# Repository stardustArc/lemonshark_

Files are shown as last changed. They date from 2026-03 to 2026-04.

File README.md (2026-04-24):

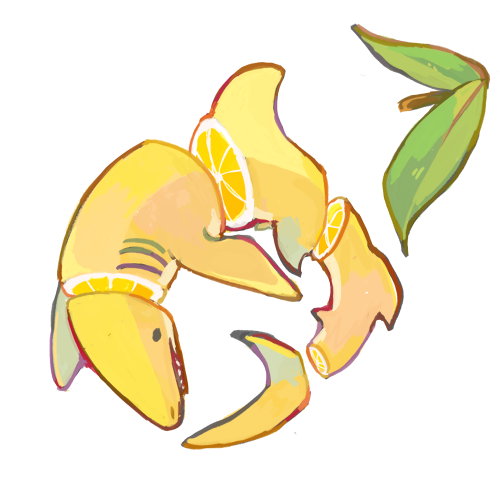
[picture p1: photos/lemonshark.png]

# lemonshark

a wireless split keyboard with per-key RGB and nice!view displays

---
## to do
- [ ] write readme (this is gonna take a lot of commits lol)
- [ ] upload images/gallery
- [ ] modify logo image to be cleaner (light mode jumpscare rn)
- [ ] create v2 PCB
- [ ] build guide?
- [ ] user-mods/cases (pyntie's case + plateless + OLED-compatible display cover)
- [ ] clean up ZMK config/readme/keymap (need to add link to this)

---
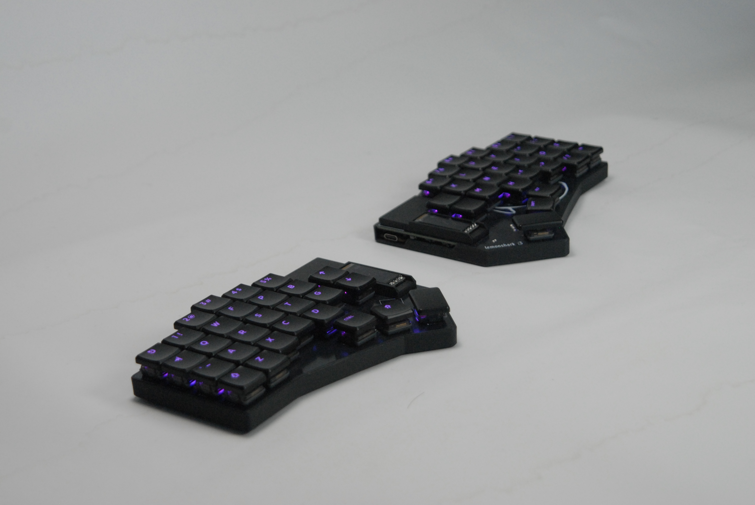
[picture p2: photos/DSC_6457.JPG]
main photo


▲ lemonshark with plateless case, RGB, and MBK glow

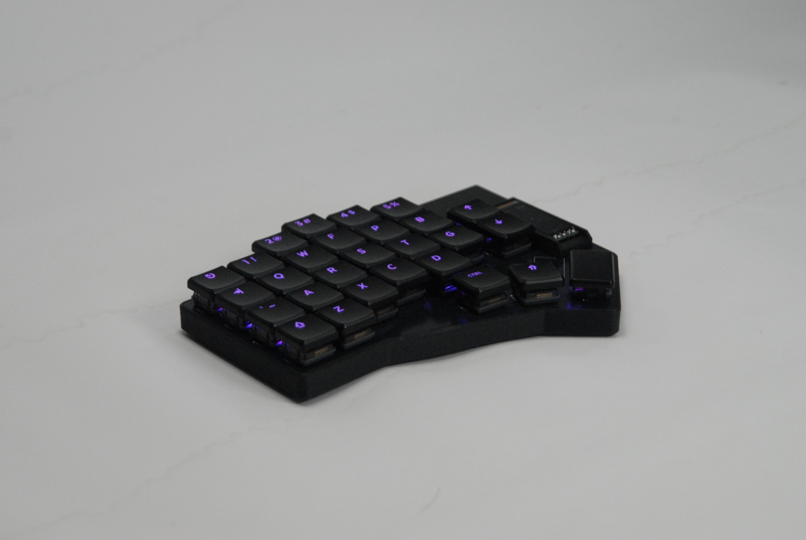
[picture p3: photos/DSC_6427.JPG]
left_RGB


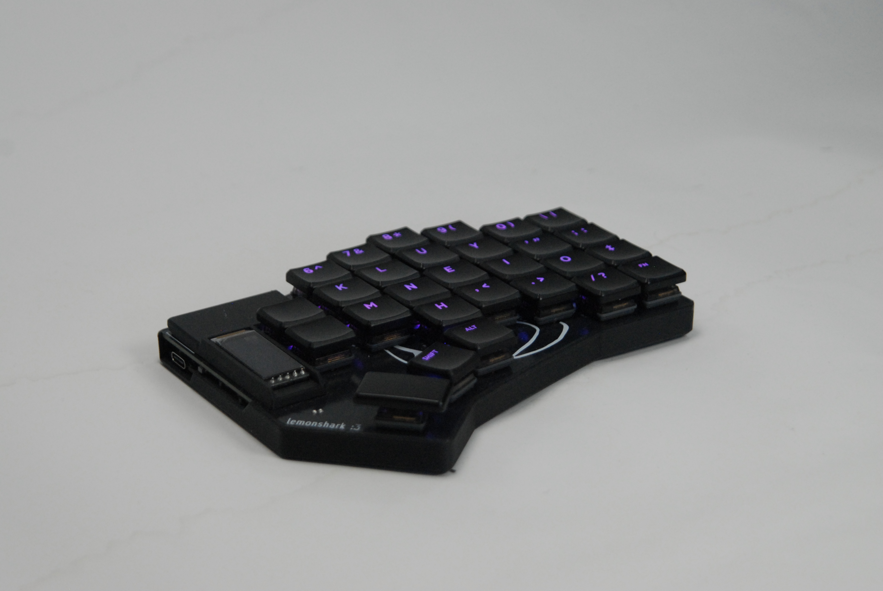
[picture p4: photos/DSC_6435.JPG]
right_RGB


---
## features:
- choc v1 compatible
- wireless
- nice!view-compatible displays
- per-key RGB
- extra-large battery

---
## ZMK config

need to clean up the [repo](https://github.com/stardustArc/zmk-config-lemonsharkv2) but here it is

---
## V1 BOM

| Part | Count | Desc | Source |
| --- | --- |--- | --- |
| Left PCB | 1 | | Your preferred fab, or message me, there's always a chance I have spare boards |
| Right PCB | 1 | | same as above |
| nice!nano v2 | 2 | MCU, though any wireless Pro Micro-based MCU will work | [Typeractive (real)](https://typeractive.xyz/products/nice-nano) or [Amazon (clone)](https://www.amazon.com/Teyleten-Robot-Development-Bluetooth-Management/dp/B0CYLNZ6V4) |
| nice!view | 2 | display, vertical SSD1306 OLEDs are also compatible | [Typeractive (nice!view)](https://typeractive.xyz/products/nice-view) or [Amazon (OLED)](https://www.amazon.com/MakerFocus-Display-SSD1306-3-3V-5V-Arduino/dp/B079BN2J8V?th=1)
| Batteries | 1 | PS3 replacement batteries, comes in a 2pk | [Amazon](https://www.amazon.com/Replacement-Playstation-Controller-CECHZC2E-CECHZC2U-3/dp/B09726K2LC) |
| Choc V1 | 56 | switches, **choc V2 NOT compatible** | [Ambient Twilights](https://lowprokb.ca/collections/switches/products/ambients-silent-choc-switches?variant=44873426436260) you don't have to use these obviously, I just like them |
| Hotswap sockets | 56 | choc hotswap switches | [Amazon](https://www.amazon.com/Mechkeeb-Kailh-Low-Hot-swappable-Socket/dp/B0BS3JYJJQ?th=1) |
| 1N4148W SOD-123F | 56 | SMD diodes, buy spares (like 60) | [Digikey](https://www.digikey.com/en/products/detail/diotec-semiconductor/1N4148W/18833653) |
| EVQ-PUA02K | 2 | reset button | [Digikey](https://www.digikey.com/en/products/detail/panasonic-electronic-components/EVQ-PUA02K/286334) |
| SSSS811101 | 4 | power switch | [Digikey](https://www.digikey.com/en/products/detail/alps-alpine/SSSS811101/19529062) |
| S2B-PH-K-S | 2 | right angle male 2mm JST-PH connector| [Digikey](https://www.digikey.com/en/products/detail/jst-sales-america-inc/S2B-PH-K-S/926626) |
| Mill-Max 310-47-112-41-001000 | 5 | machine pin header for MCU and display | [Digikey](https://www.digikey.com/en/products/detail/mill-max-manufacturing-corp/310-47-112-41-001000/7364039) |
| Mill-Max 3320-0-00-15-00-00-03-0 | 65 | pins for headers, this count includes 7 spares | [Digikey](https://www.digikey.com/en/products/detail/mill-max-manufacturing-corp/3320-0-00-15-00-00-03-0/4147392) |
| Adafruit MiniBoost 5V TPS61023 | 2 | level shifter for LEDs | [Digikey](https://www.digikey.com/en/products/detail/adafruit-industries-llc/4654/12697636) |
| SK6812 Mini-E | 56 | LEDs, best to use SK6803 but it's not what I had, plus these were dirt cheap | [Amazon](https://www.amazon.com/Lizusidtsy-Similar-Individually-Addressable-500076361/dp/B0D62PYX62) |
| Keycaps of your choice | 56 | 54 1u keys, 2 1.5u keys. Choc-spaced | take your pick! MBK Legends Glow R1 for me |
| Case | 2 | one of each half | located in this repository |

---
## Credits

A massive thank you to the MrZealot and [Ceoloide](https://github.com/ceoloide) for creating and maintaining [Ergogen](https://ergogen.xyz), the software with which lemonshark was created. The [Absolem Club discord](http://discord.ergogen.xyz/) was irreplacable for help of all sorts, as was FlatFootFox with his [writeup](https://flatfootfox.com/ergogen-introduction/) on Ergogen. Additonally, thank you to car, Evelyn, [Peter](https://github.com/peterjc/), Fox, Turtlyn, and [Grinnie](https://github.com/regicidalplutophage) from Absolem Club, they were all a massive help in getting through this monumental project.

Thanks to Genteure and their [ZMK Shield Wizard](https://shield-wizard.genteure.workers.dev/), it made configuring ZMK a breeze. Also, thanks to the entire team behind the [ZMK firmware](https://zmk.dev), one of the main goals of this board wouldn't be possible without you.

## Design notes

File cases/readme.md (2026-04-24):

## cases

--- 

lemonshark currently has two case options:
  - a low profile, hardwareless case which fits both the nice!view and other OLEDs. Requires some foam strips to secure the battery.
    (insert photo here. this is the case found on the main readme)
    
  - a case by PyntieHet, which is far prettier but less low profile (STLs only)   (please note I do not have the files for this yet, will update when I do)
    (insert photo here)

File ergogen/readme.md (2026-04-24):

# Ergogen stuff

---

lemonshark was created in Ergogen, with silkscreens and level shifter added in KiCAD.

Here are all of the local footprint I used, along with the config file.
I plan on cleaning up the config file at some point, it's pretty messy right now.

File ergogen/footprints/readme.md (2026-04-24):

You will need to import the following footprints into Ergogen and rename them so that the footprint name is the same as the file name. 

---
## Note:

These footprints _should_ all render in KiCavas, I've updated them all to KiCAD 8.

Additionally, the level shift was a custom footprint I designed in KiCAD, I've since lost the footprint as my laptop's SSD decided to die.

(I plan on either not requiring the level shifter or writing my own Ergogen footprint for it for V2)

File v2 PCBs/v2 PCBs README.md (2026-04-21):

# Coming soon!
---

As of right now, a v2 board is planned but not yet designed or fabbed. I don't really recommend building v1, so check back here in the next few months to see if there's been an update.

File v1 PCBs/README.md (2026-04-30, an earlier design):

# V1 PCBs
---
V1 PCB and various files are now uploaded!

If you want to build your own lemonshark board, please use the V2 PCB (coming soon!). V1 currently has a few issues (various bodges and janky solutions) and is only uploaded for reference purposes.

**The build guide uses a V1 PCB** <- build guide coming soon
this is just because i don't have a V2 PCB on hand, and probably won't for a while. However, if and when I do obtain a V2 PCB, i will create another build guide for V2.

UPDATE: V1.1 PCBs uploaded, these have replaced V1. This eliminates bodges, but is still limited to running choc V1 only and LEDs through a level shifter

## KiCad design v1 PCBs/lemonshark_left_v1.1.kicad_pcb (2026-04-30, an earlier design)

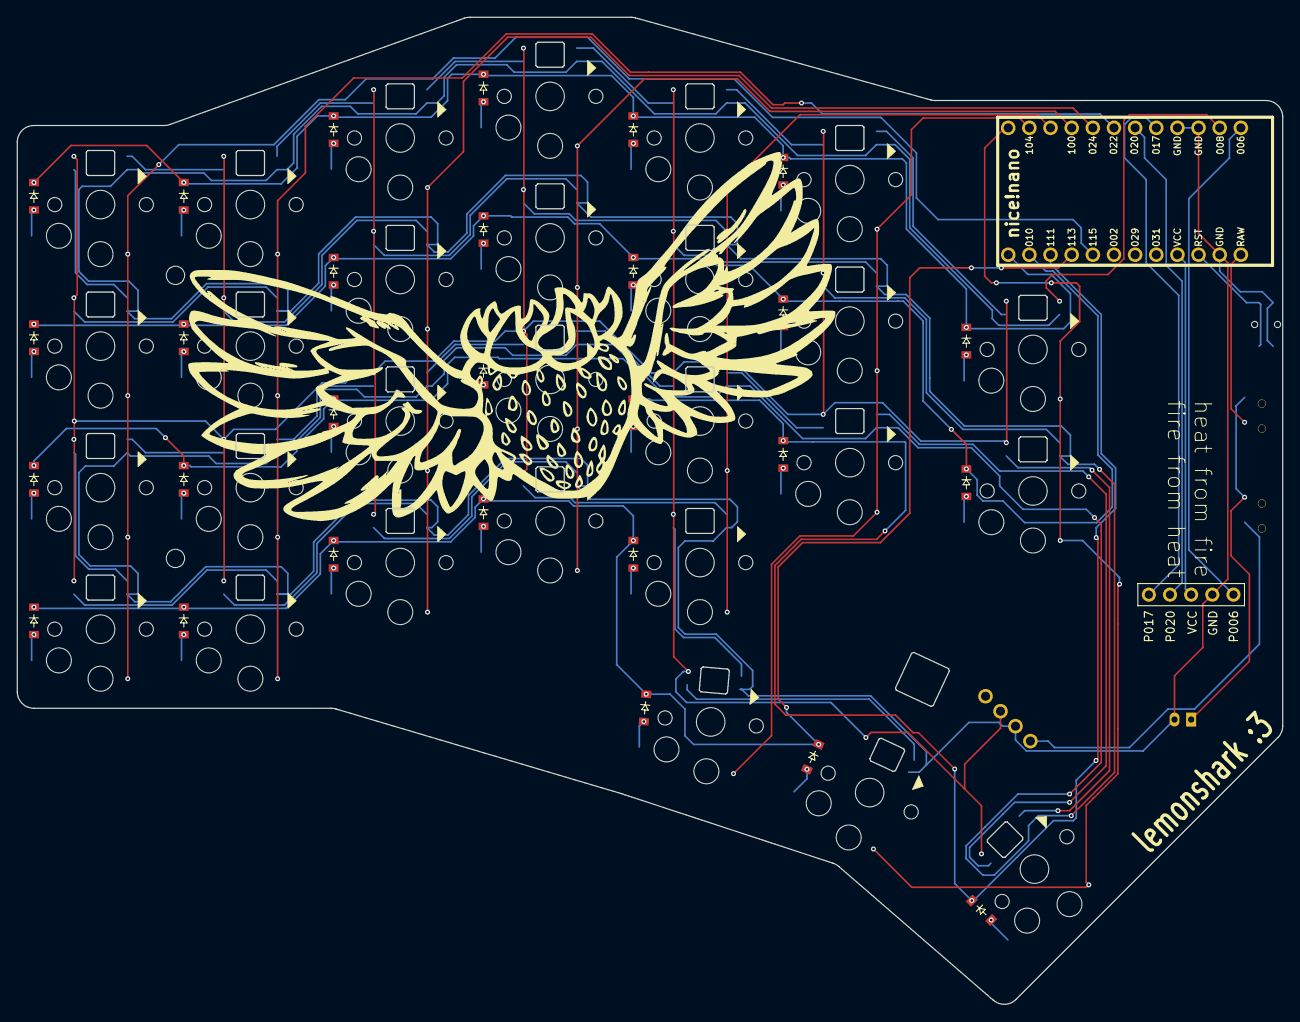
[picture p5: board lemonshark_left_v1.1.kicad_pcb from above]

Board: 2 copper layers, 152.0 x 118.6 mm, 92 parts (0 on the bottom side), 50 nets.

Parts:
B1: Panasonic_EVQPUL_EVQPUC
D1, D2, D3, D4, D5, D6, D7, D8, D9, D10, D11, D12, D13, D14, D15, D16, D17, D18, D19, D20, D21, D22, D23, D24, D25, D26, D27, D28: ComboDiode
DISP1: display_nice_view
JST1: JST_PH_S2B-PH-K_02x2.00mm_Angled
LED1, LED2, LED3, LED4, LED5, LED6, LED7, LED8, LED9, LED10, LED11, LED12, LED13, LED14, LED15, LED16, LED17, LED18, LED19, LED20, LED21, LED22, LED23, LED24, LED25, LED26, LED27, LED28: WS2812B
MCU1: nice_nano
MH1, MH2: mounting_hole_npth
S1, S2, S3, S4, S5, S6, S7, S8, S9, S10, S11, S12, S13, S14, S15, S16, S17, S18, S19, S20, S21, S22, S23, S24, S25, S26, S27, S28: PG1350
T1, T2: SPDT_C128955

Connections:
5v: LED1.1, LED2.1, LED3.1, LED4.1, LED5.1, LED6.1, LED7.1, LED8.1, LED9.1, LED10.1, LED11.1, LED12.1, LED13.1, LED14.1, LED15.1, LED16.1, LED17.1, LED18.1, LED19.1, LED20.1, LED21.1, LED22.1, LED23.1, LED24.1, LED25.1, LED26.1, LED27.1, LED28.1
GND: B1.1, DISP1.4, JST1.2, LED1.3, LED2.3, LED3.3, LED4.3, LED5.3, LED6.3, LED7.3, LED8.3, LED9.3, LED10.3, LED11.3, LED12.3, LED13.3, LED14.3, LED15.3, LED16.3, LED17.3, LED18.3, LED19.3, LED20.3, LED21.3, LED22.3, LED23.3, LED24.3, LED25.3, LED26.3, LED27.3, LED28.3, MCU1.3, MCU1.4, MCU1.23
P006: DISP1.5, MCU1.1
P008: LED2.4, MCU1.2
P009: D2.1, D5.1, D9.1, D13.1, D17.1, D21.1, D25.1, MCU1.13
P010: D1.1, D4.1, D8.1, D12.1, D16.1, D20.1, D24.1, MCU1.14
P011: MCU1.10, S6.1, S7.1, S8.1, S9.1
P017: DISP1.1, MCU1.5
P020: DISP1.2, MCU1.6
P022: MCU1.7, S18.1, S19.1, S20.1, S21.1
P024: MCU1.8, S14.1, S15.1, S16.1, S17.1
P100: MCU1.9, S10.1, S11.1, S12.1, S13.1
P104: MCU1.11, S3.1, S4.1, S5.1, S28.1
P106: MCU1.12, S1.1, S2.1, S26.1, S27.1
P111: D3.1, D7.1, D11.1, D15.1, D19.1, D23.1, D26.1, MCU1.15
P113: D6.1, D10.1, D14.1, D18.1, D22.1, D27.1, D28.1, MCU1.16
P115: MCU1.17, S22.1, S23.1, S24.1, S25.1
RAW: MCU1.24, T1.2
RST: B1.2, MCU1.22
VCC: DISP1.3, MCU1.21
mirror_index_bottom: D6.2, S6.2
mirror_index_home: D7.2, S7.2
mirror_index_num: D9.2, S9.2
mirror_index_top: D8.2, S8.2
mirror_inner_home: D3.2, S3.2
mirror_inner_num: D5.2, S5.2
mirror_inner_top: D4.2, S4.2
mirror_left_mod: D27.2, S27.2
mirror_math_num: D2.2, S2.2
mirror_math_top: D1.2, S1.2
mirror_middle_bottom: D10.2, S10.2
mirror_middle_home: D11.2, S11.2
mirror_middle_num: D13.2, S13.2
mirror_middle_top: D12.2, S12.2
mirror_outer_bottom: D22.2, S22.2
mirror_outer_home: D23.2, S23.2
mirror_outer_num: D25.2, S25.2
mirror_outer_top: D24.2, S24.2
mirror_pinky_bottom: D18.2, S18.2
mirror_pinky_home: D19.2, S19.2
mirror_pinky_num: D21.2, S21.2
mirror_pinky_top: D20.2, S20.2
mirror_right_mod: D28.2, S28.2
mirror_ring_bottom: D14.2, S14.2
mirror_ring_home: D15.2, S15.2
mirror_ring_num: D17.2, S17.2
mirror_ring_top: D16.2, S16.2
mirror_space_mod: D26.2, S26.2
pos: JST1.1, T1.1, T2.1
undefined: LED1.2, LED1.4, LED2.2, LED3.2, LED3.4, LED4.2, LED4.4, LED5.2, LED5.4, LED6.2, LED6.4, LED7.2, LED7.4, LED8.2, LED8.4, LED9.2, LED9.4, LED10.2, LED10.4, LED11.2, LED11.4, LED12.2, LED12.4, LED13.2, LED13.4, LED14.2, LED14.4, LED15.2, LED15.4, LED16.2, LED16.4, LED17.2, LED17.4, LED18.2, LED18.4, LED19.2, LED19.4, LED20.2, LED20.4, LED21.2, LED21.4, LED22.2, LED22.4, LED23.2, LED23.4, LED24.2, LED24.4, LED25.2, LED25.4, LED26.2, LED26.4, LED27.2, LED27.4, LED28.2, LED28.4

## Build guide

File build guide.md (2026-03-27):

TODO
- sokdering walkthrough
- firmware
- casse

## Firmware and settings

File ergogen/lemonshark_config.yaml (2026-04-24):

units:
  #choc
  gx: cx
  gy: cy
  gpx: gx + 2
  gpy: gy + 2
  $default_width: cx
  $default_height: cy
  screwThreadRadius: 0.5
  screwPCBRadius: 4.0
points:
  zones:
    matrix:
      anchor:
        shift: [190, -150]
      key:
        padding: gy
        spread: gx
      columns:
        math:
          rows.home.shift: [-4, -1.2cy]
          rows.bottom.skip: true
          rows.home.skip: true
          key.column_net: P009
          key.mirror.column_net: P106 
        inner:
          rows.bottom.skip: true
          key.column_net: P010
          key.mirror.column_net: P104
        index:
          key.stagger: 5
          key.column_net: P111
          key.mirror.column_net: P011
        middle:
          key.stagger: 5
          key.column_net: P113
          key.mirror.column_net: P100
        ring:
          key.stagger: -5
          key.column_net: P115 
          key.mirror.column_net: P024
        pinky:
          key.stagger: -8
          key.column_net: P002
          key.mirror.column_net: P022
        outer:
          key.column_net: P029
          key.mirror.column_net: P115
      rows:
        #mod:
          #row_net: P024
        bottom:
          row_net: P100
          mirror.row_net: P113 
        home:
          row_net: P011
          mirror.row_net: P111
        top:
          row_net: P104
          mirror.row_net: P010
        num:
          row_net: P106
          mirror.row_net: P009
    thumb:
      anchor:
        ref: matrix_inner_bottom
        rotate: 45
        shift: [-19, -35]
      key:
        padding: gy
        spread: gx
      #columns:
        #left:
          #key.row_net: P009
        #right:
          #key.row_net: P010
      #rows:
        #mod:
          #column_net: P104
      columns:
        space:
          key.rotate: -90
          key.width: 1.5cx
          key.shift: [0, 0.25cx]
          key.row_net: P011
          key.column_net: P009
          key.mirror.row_net: P111
          key.mirror.column_net: P106
        left:
          key.rotate: -20
          key.shift: [2.5, -3]
          key.row_net: P100
          key.column_net: P009
          key.mirror.row_net: P113
          key.mirror.column_net: P106
        right:
          key.rotate: -40
          key.shift: [4,-10.5]
          key.row_net: P100
          key.column_net: P010
          key.mirror.row_net: P113
          key.mirror.column_net: P104
      rows:
        mod:
    #space:
      #anchor:
        #ref: thumb_right_mod
        #shift: [-4, -19]
        
      #key:
        #padding: gy
        #spread: gx
      #columns:
        #space:
          #key.width: 1.5cx
          #key.column_net: P009
          #key.rotate: 5
      #rows:
        #space:
          #row_net: P024
   

  #rotate: 10
  #mirror: &mirror
    #ref: space_space_space
    #distance: -120

  mirror: &mirror
    ref: matrix_math_num
    distance: -3gx

outlines:
  raw:
    - what: rectangle
      where: true
      size: [gpx, gpy]
  keys:
    - what: rectangle
      where: true
      size: [gx-0.5, gy-0.5]
  board:
    - what: polygon
      operation: stack
      points:
        - ref: matrix_outer_num
          shift: [0.5gpx, 0.5gpy]
        - ref: matrix_pinky_num
          shift: [ 0.5gpx, 0.5gpy]
        - ref: matrix_middle_num
          shift: [0.5gpx, 0.5gpy]
        - ref: matrix_middle_num
          shift: [-0.5gpx, 0.5gpy]
        #- ref: matrix_index_num
          #shift: [-0.5gpx, 0.5gpy]
        #- ref: matrix_inner_num
          #shift: [0, 0]
        - ref: matrix_inner_num
          shift: [-0.5gpx, 0.5gpy]
        - ref: matrix_math_num
          shift: [-30, 29.9]
        - ref: thumb_space_mod
          shift: [-32.66905, -9.5]
        - ref: thumb_space_mod
          shift: [14.5, -9.5]
        #- ref: thumb_space_mod
          #shift: [14.5,35.80761]
        - ref: thumb_left_mod
          shift: [0, -0.5gpy]
        - ref: thumb_right_mod
          shift: [0.5gpx, -0.5gpy]
        #- ref: matrix_index_bottom
          #shift: [0.5gpx, -0.5gpy]
        #- ref: matrix_ring_bottom
          #shift: [-0.5gpx, -0.5gpy]
        - ref: matrix_pinky_bottom
          shift: [-0.5gpx, -0.5gpy]
        - ref: matrix_outer_bottom
          shift: [0.5gpx, -0.5gpy]
      fillet: 2
  combo:
    - name: board
    - operation: subtract
      name: keys
  #reverse mount LED holes   
  LEDs: 
    - what: rectangle
      size: [3.4, 3]
      bevel: 0.2
      operation: add
      where: true
      adjust:
        shift: [0, 5]

  standoff:
    - what: rectangle
      size: [5, 5]
      bevel: 0.2
      operation: add
      where: /thumb_left_mod*/
      adjust:
        shift: [0, 15]

  LED_holes:
    - name: standoff
    - operation: add
      name: LEDs
    
  #board with LED cutouts
  board_LED:
    - name: board
    - operation: subtract
      name: LED_holes
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

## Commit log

2026-03-27 Create V1 PCBs README
2026-03-27 Update and rename V1 PCBs README to V1 PCBs README.md
2026-04-21 Update V1 PCBs README.md
2026-04-21 Create v2 PCBs README.md
2026-04-21 Update v2 PCBs README.md
2026-04-24 added v1 PCB files
    [lemonshark_left.kicad_pcb, lemonshark_right.kicad_pcb]
2026-04-24 Update and rename V1 PCBs README.md to README.md
2026-04-24 Create gerbers
2026-04-24 added footprints
2026-04-24 Update README.md
    added BOM (i hope the formatting is right), messed with credits
2026-04-30 uploaded v1.1 files
    [lemonshark_left_v1.1.kicad_pcb, lemonshark_right_v1.1.kicad_pcb]
2026-04-30 added v1.1 gerbers
